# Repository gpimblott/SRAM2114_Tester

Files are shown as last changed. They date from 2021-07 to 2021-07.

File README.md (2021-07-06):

# 2114 SRAM Tester

Tester for 2114 SRAM chips using an Arduino Nano. The code can be loaded into the standard Arduino IDE for uploading/editing.

2114 SRAM chips are used in the ZX81, they are 4096 bit chips arranged in 1024 rows of 4 bits.  This code uses a Arduino Nano to perform various tests on a 2114 chip to check that it is working.

The prototype wiring (v01) is outlined in the table below

Port | Arduino  |  2114
-----|----------|--------
PC0  |A0        |IO1
PC1  |A1        |IO2
PC2  |A2        |IO3
PC3  |A3        |IO4
PC4  |A4        |Green LED
PC5  |A5        |Red LED
PC6  |A6        |Switch
PD0  |0         |Serial (Debug) - leave empty for USB
PD1  |1         |Serial (Debug) - leave empty for USB
PD2  |2         |/CS (Chip Select)
PD3  |3         |/WE (Write Enabled)
PD4  |4         |A0
PD5  |5         |A1
PD6  |6         |A2
PD7  |7         |A3
PB0  |8         |A4
PB1  |9         |A5
PB2  |10        |A6
PB3  |11        |A7
PB4  |12        |A8
PB5  |13        |A9

The project is currently is currently at the prototype stage but I am working on a PCB design which should hopefully be available soon.

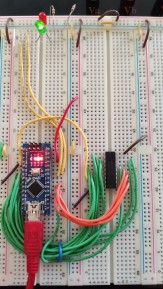
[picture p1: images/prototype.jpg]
Prototype


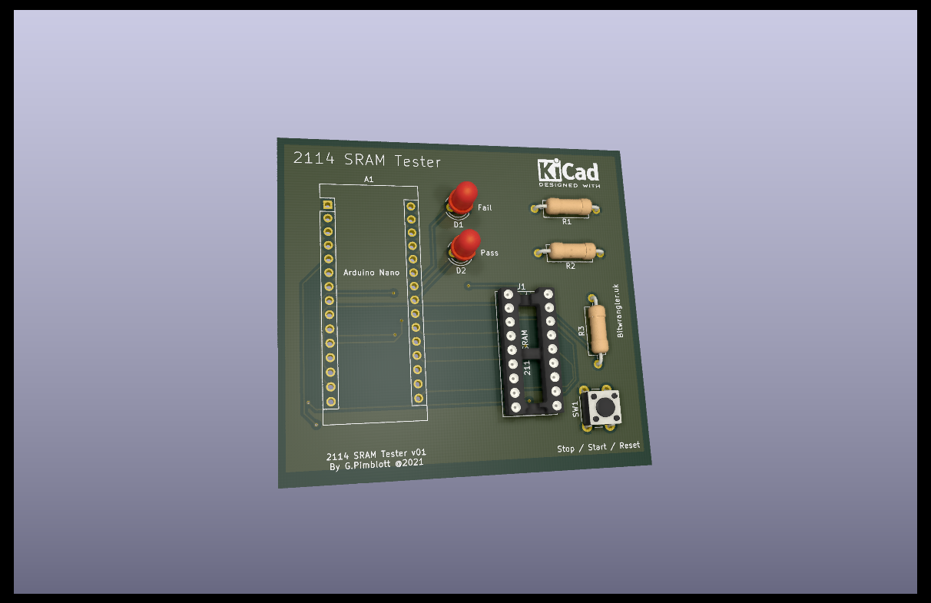
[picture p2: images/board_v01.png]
Kicad board design


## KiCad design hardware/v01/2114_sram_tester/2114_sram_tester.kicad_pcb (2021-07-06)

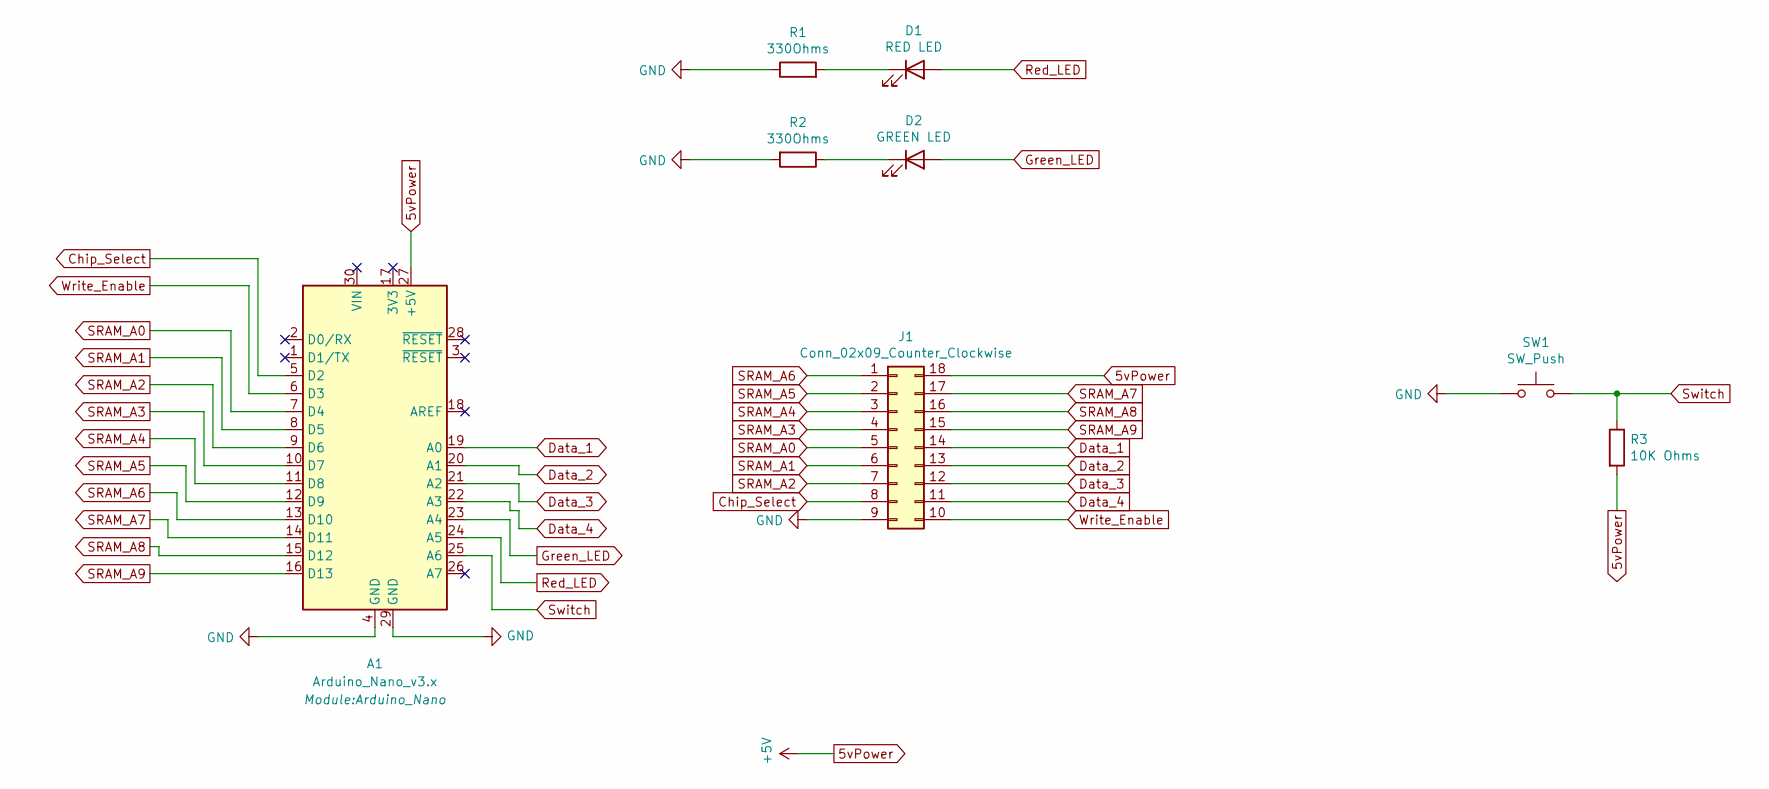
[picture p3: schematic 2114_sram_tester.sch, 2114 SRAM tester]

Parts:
A1: Arduino_Nano_v3.x; Arduino_Nano
D1: RED LED; LED_D4.0mm
D2: GREEN LED; LED_D4.0mm
J1: Conn_02x09_Counter_Clockwise; DIP-18_W7.62mm_Socket
R1, R2: 330Ohms; R_Axial_DIN0309_L9.0mm_D3.2mm_P12.70mm_Horizontal
R3: 10K Ohms; R_Axial_DIN0309_L9.0mm_D3.2mm_P12.70mm_Horizontal
SW1: SW_Push; SW_PUSH_6mm

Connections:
5vPower: A1.27 (+5V), J1.18, R3.2
Chip_Select: A1.5 (D2), J1.8
Data_1: A1.19 (A0), J1.14
Data_2: A1.20 (A1), J1.13
Data_3: A1.21 (A2), J1.12
Data_4: A1.22 (A3), J1.11
GND: A1.4 (GND), A1.29 (GND), J1.9, R1.1, R2.2, SW1.1
Green_LED: A1.23 (A4), D2.2 (A)
unnamed: D1.1 (K), R1.2
unnamed: D2.1 (K), R2.1
Red_LED: A1.24 (A5), D1.2 (A)
SRAM_A0: A1.7 (D4), J1.5
SRAM_A1: A1.8 (D5), J1.6
SRAM_A2: A1.9 (D6), J1.7
SRAM_A3: A1.10 (D7), J1.4
SRAM_A4: A1.11 (D8), J1.3
SRAM_A5: A1.12 (D9), J1.2
SRAM_A6: A1.13 (D10), J1.1
SRAM_A7: A1.14 (D11), J1.17
SRAM_A8: A1.15 (D12), J1.16
SRAM_A9: A1.16 (D13), J1.15
Switch: A1.25 (A6), R3.1, SW1.2
Write_Enable: A1.6 (D3), J1.10

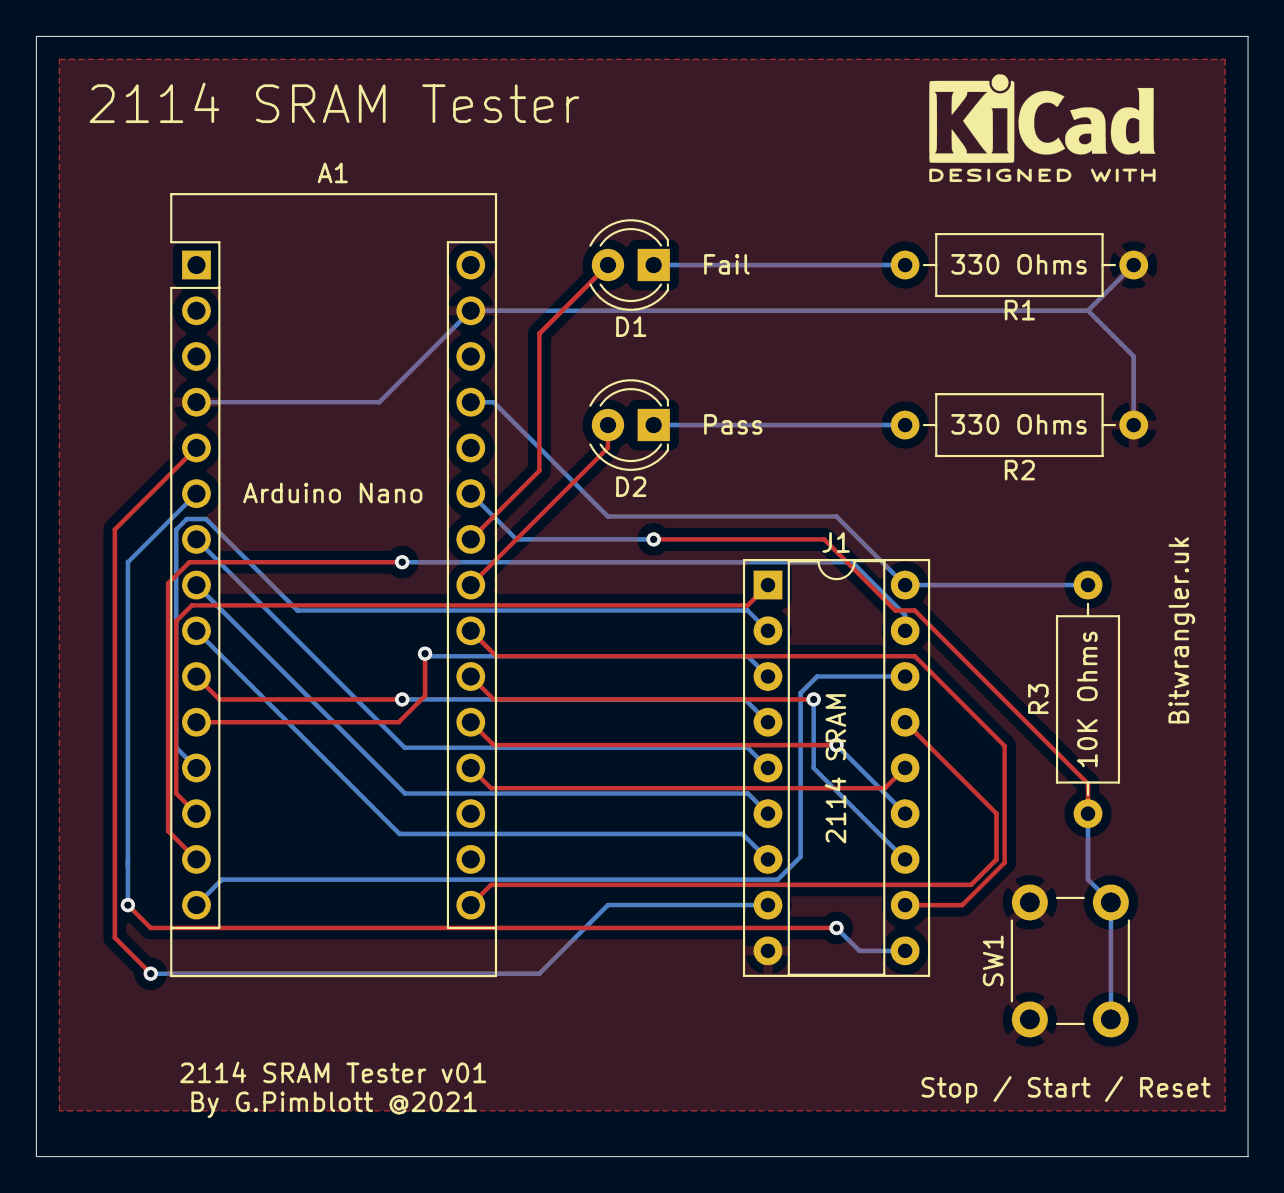
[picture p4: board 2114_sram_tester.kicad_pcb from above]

Board: 2 copper layers, 67.3 x 62.2 mm, 8 parts (0 on the bottom side), 23 nets.

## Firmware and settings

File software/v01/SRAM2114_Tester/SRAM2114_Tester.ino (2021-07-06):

/**
   Basic 2114 Static RAM tester

   The 2114 is a 4096 bit static ram chip organised as 1024 4 bit values
   This type of RAM is used on the ZX81.

   Both LED's are lit for 1 second at startup.
   The button can then be used to start/start testing.
   The green led flashes during testing
   The red led will be lit following a test failure
   Both leds will be off when tests are not running
*/

/*
   Some standard timings for 2144 Static RAM chips
   ------------------------------------------------
   Minimum write pulse time = 150ns
   Data setup time = 150ns
   Write cycle time = 300ns

   PIN definitions

   Port Arduino   2114
   -------------------
   PC0  A0        IO1
   PC1  A1        IO2
   PC2  A2        IO3
   PC3  A3        IO4

   LEDs & Pushbutton
   -------------------
   PC4  A4        Green LED
   PC5  A5        Red LED

   // A6 & A7 can only be analog inputs and don't have internal pulls
   // But that's all I have left to work with
   PC6  A6        Switch

   Special
   -------------------
   PD0  0         Serial (Debug) - leave empty for USB
   PD1  1         Serial (Debug) - leave empty for USB
   PD2  2         /CS (Chip Select)
   PD3  3         /WE (Write Enabled)

   Address lines
   -------------------
   PD4  4         A0
   PD5  5         A1
   PD6  6         A2
   PD7  7         A3
   PB0  8         A4
   PB1  9         A5
   PB2  10        A6
   PB3  11        A7
   PB4  12        A8
   PB5  13        A9
*/
#define MAX_ADDRESS 1024
#define MAX_VALUE 16
#define NUM_BITS 4

// Data pins
#define DATA_PINS 0b00001111    // A0...A3

// LED pins
#define GREEN_LED  0b00010000   // A4
#define RED_LED    0b00100000   // A5

// The serial pins are PD0 and PD1
#define SERIAL_PINS 0b00000011  // D0 & D1

// RAM pins
#define RAM_CS     0b00000100  // Active Low - D2
#define RAM_WE     0b00001000  // Active Low - D3

// Helper Macros for the LEDS
#define green_led_on()  PORTC |= GREEN_LED
#define green_led_off() PORTC &= ~GREEN_LED
#define toggle_green_led() PORTC ^= GREEN_LED

#define red_led_on()    PORTC |= RED_LED
#define red_led_off()   PORTC &= ~RED_LED

// NB: CS and WE are active low so ON==0 and OFF==1
// We don't want to mess with the serial pins on PD0 and PD1 so mask them off
#define enable_cs()     PORTD &= (~RAM_CS)
#define disable_cs()    PORTD |= (RAM_CS | SERIAL_PINS)

#define enable_we()     PORTD &= (~RAM_WE)
#define disable_we()    PORTD |= (RAM_WE | SERIAL_PINS)

#define disable_ram()   PORTD |= (RAM_WE | RAM_CS | SERIAL_PINS)

#define data_in()       DDRC = RED_LED | GREEN_LED;               // LED's output rest input
#define data_out()      DDRC = RED_LED | GREEN_LED | DATA_PINS;   // 0110 1111 - ALL Output except switch

#define SWITCH_PIN  A6

/**
   Global variables
*/
enum stateModel {
  stopped,
  running,
  failed
};

stateModel test_running = stopped;

// Button debounce variables
boolean buttonValue = false;
boolean previousButtonValue = false;
unsigned long lastDebounceTime = 0L;
unsigned long debounceDelay = 50;

/**
   Setup the direction of the pins
   Disable CS and WE ready to start running tests
*/
void setup() {
  // Setup the serial debug
  Serial.begin(115200);

  // IO pins*4 (IN = 0) and LED pins*2 (OUT = 1)
  DDRC = RED_LED | GREEN_LED;
  // All output but leave serial lines alone (PD0 and PD1)
  DDRD |=  0b11111100;     // 1111 1100
  // A4-A9 outputs
  DDRB = 0b00111111;       // 0011 1111

  // define switch with internal pullup
  pinMode( SWITCH_PIN, INPUT );

  // Set the initial state of the Chip select and write enabled to OFF
  disable_cs();
  disable_we();

  Serial.println("Ready");
  green_led_on();
  red_led_on();

  delay(1000);
  set_test_state(stopped);
}

/**
   Run the main test loop
*/
void loop() {
  check_button();

  if ( test_running == running ) {
    toggle_green_led();
    
    if (!test_sequence() ) {
      Serial.println("Sequence test failed");
      set_test_state( failed );
    }
    else if (!test_sequence2() ) {
      Serial.println("Sequence2 test failed");
      set_test_state( failed );
    }
    else if (!test_sliding_bit() ) {
      Serial.println("Sliding bit test failed");
      set_test_state( failed );
    }
    else if (!test_checker_board() ) {
      Serial.println("Checker board test failed");
      set_test_state( failed );
    }
  }
}

/*
   Check if the button has been pressed
   Includes simple button debounce
*/
void check_button() {
  boolean pressed = false;

  if ( analogRead(SWITCH_PIN) <= 10 ) {
    pressed = true;
  }

  if ( pressed && !previousButtonValue) {
    lastDebounceTime = millis();
  }

  if ((millis() - lastDebounceTime) > debounceDelay) {
    if ( pressed && !buttonValue) {
      switch ( test_running ) {
        case running :
          set_test_state( stopped );
          break;
        case stopped :
          set_test_state( running );
          break;
        case failed :
          set_test_state( stopped );
          break;
      }
    }
    buttonValue = pressed;
  }
  previousButtonValue = pressed;
}

/**
   Set the status of the LEDS and whether the tests are running
*/
void set_test_state(stateModel state) {
  switch (state) {
    case stopped :
      green_led_off();
      red_led_off();
      Serial.println("Test state : stopped");
      break;
    case running :
      green_led_on();
      red_led_off();
      Serial.println("Test state : running");
      break;
    case failed :
      green_led_off();
      red_led_on();
      Serial.println("Test state : failed");
      break;
  }

  test_running = state;
}

/*********************************************************
   Tests to execute
 *********************************************************/

/*
   Write an incrementing value to each consecutive memory location
   and read it back immediately
*/
boolean test_sequence() {
  byte test_data = 0;
  for (word address = 0; address < MAX_ADDRESS ; address++) {
    test_data = address % MAX_VALUE;
    if (!test_write_read( address, test_data)) {
      return false;
    }
  }
  return true;
}

/**
   Write a to each memory location then read them all back
*/
boolean test_sequence2() {
  byte test_data = 0;
  for (word address = 0; address < MAX_ADDRESS ; address++) {
    test_data = address % MAX_VALUE;
    write_data_to_address(address, test_data);
  }

  set_data(0);

  for (word address = 0; address < MAX_ADDRESS ; address++) {
    test_data = address % MAX_VALUE;
    byte result = read_data_at_address(address);
    if ( result != test_data) {
      output_test_result(address, test_data, result);
      return false;
    }
  }

  return true;
}

/*
   Slide a bit through each position for each location
*/
boolean test_sliding_bit() {
  for (word address = 0; address < MAX_ADDRESS; address++ ) {
    for (int x = 0; x <= NUM_BITS; x++) {
      byte data = (1 << x) & 0b00001111;
      if ( !test_write_read( address , data)) {
        return false;
      }
    }
  }

  return true;
}

boolean test_checker_board() {
  byte pattern = 0b00000101;
  for (word address = 0; address < MAX_ADDRESS; address++ ) {
    if (!test_write_read(address, pattern)) {
      return false;
    }
    pattern = ~pattern & 0b00001111;
  }

  pattern = 0b00000101;
  for (word address = 0; address < MAX_ADDRESS; address++ ) {
    byte result = read_data_at_address( address );
    if ( pattern != result ) {
      output_test_result( address, pattern , result );
      return false;
    }
    pattern = ~pattern & 0b00001111;
  }
  return true;
}

/*****************************************************
   Utility test routines
 *****************************************************/
boolean test_write_read( word address, byte value ) {
  write_data_to_address( address , value );
  byte result = (byte)read_data_at_address(address);
  if ( result != value) {
    output_test_result(address , value, result);
    return false;
  }
  return true;
}

void output_test_result( word address, byte expected, byte returned) {
  Serial.print("Address (");
  Serial.print(address);
  Serial.print(") : expected (");
  Serial.print(expected, BIN);
  Serial.print(") -> Returned (");
  Serial.print(returned, BIN);
  Serial.println(")");
}


/************************************************
   Bit bashing routines to read and write data
 ************************************************/
void set_address(word address) {
  // Mask first 4 bits to avoid serial and CS/WE then
  PORTD &= 0b00001111;
  PORTD |= (byte)(0b00001111 & address) << 4;

  PORTB &= 0b11000000;
  PORTB |= (byte)(0b00111111 & (address >> 4));
}

void set_data(byte data) {
  PORTC &= 0b11110000;
  PORTC |= (data & 0b00001111);
}

byte get_data() {
  byte data = (PINC & 0b00001111);
  return data;
}

/*
   Write the data to the specified address
*/
void write_data_to_address(word address, byte data) {
  disable_ram();
  data_out();

  set_address(address);
  set_data(data);

  enable_cs();
  enable_we();

  // Wait for write = 300ns - a NOP is 62.5ns
  asm("NOP");
  asm("NOP");
  asm("NOP");
  asm("NOP");
  asm("NOP");
  asm("NOP");

  disable_ram();
}

/*
   Read the data at the specified address
   The data will be in the low bits of the byte
*/
byte read_data_at_address(word address) {

  disable_ram();
  data_in();

  set_address(address);
  enable_cs();

  // Wait for read = 150ns - a NOP is 62.5ns assuming 16Mhz clock
  asm("NOP");
  asm("NOP");
  asm("NOP");
  asm("NOP");

  byte data = get_data();
  disable_ram();

  return data;
}

/*
   Debug output routines
*/
void output_debug() {
#ifdef DEBUG

  byte port = PORTD;
  boolean chip_select = !(port & 0b00000100);
  boolean write_enabled = !(port & 0b00001000);

  Serial.print("/CS : ");
  Serial.println( chip_select ? "ON" : "OFF");
  Serial.print("/WE : ");
  Serial.println( write_enabled ? "ON" : "OFF");
#endif
}

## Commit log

2021-07-04 Add KiCad files
    Initial work on Kicad board design
    [2114_sram_tester.kicad_pcb, 2114_sram_tester.sch]
2021-07-04 Added prototype image
2021-07-06 Added button code
    Button added to stop/start tests
    [2114_sram_tester.sch]
2021-07-06 Updated hardware
    Updated hardware to include stop/start button
    [2114_sram_tester.kicad_pcb]
2021-07-06 Updated hardware
    [2114_sram_tester.sch]
2021-07-06 Generated Gerber export files and zip
    Generated the necessary files to have a test board made
    [2114_sram_tester-B_Cu.gbr, 2114_sram_tester-B_Mask.gbr, 2114_sram_tester-B_Paste.gbr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]
2021-07-06 Change structure
    Move gerber files to root directory
    [2114_sram_tester-B_Cu.gbr, 2114_sram_tester-B_Mask.gbr, 2114_sram_tester-B_Paste.gbr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]
2021-07-06 Added board picture
2021-07-06 Updated pin definitions to include switch
